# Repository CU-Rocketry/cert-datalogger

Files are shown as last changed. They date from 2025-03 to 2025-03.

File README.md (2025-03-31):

# cert-datalogger

Eggtimer Ion replica using ESP32-C3

## Features

- ESP32 MCU with WiFi and Bluetooth control and data export
- Pressure and temperature measurement
- 3.7V lithium battery compatibility
- Status LED and Buzzer

## Images

Screenshots for now:

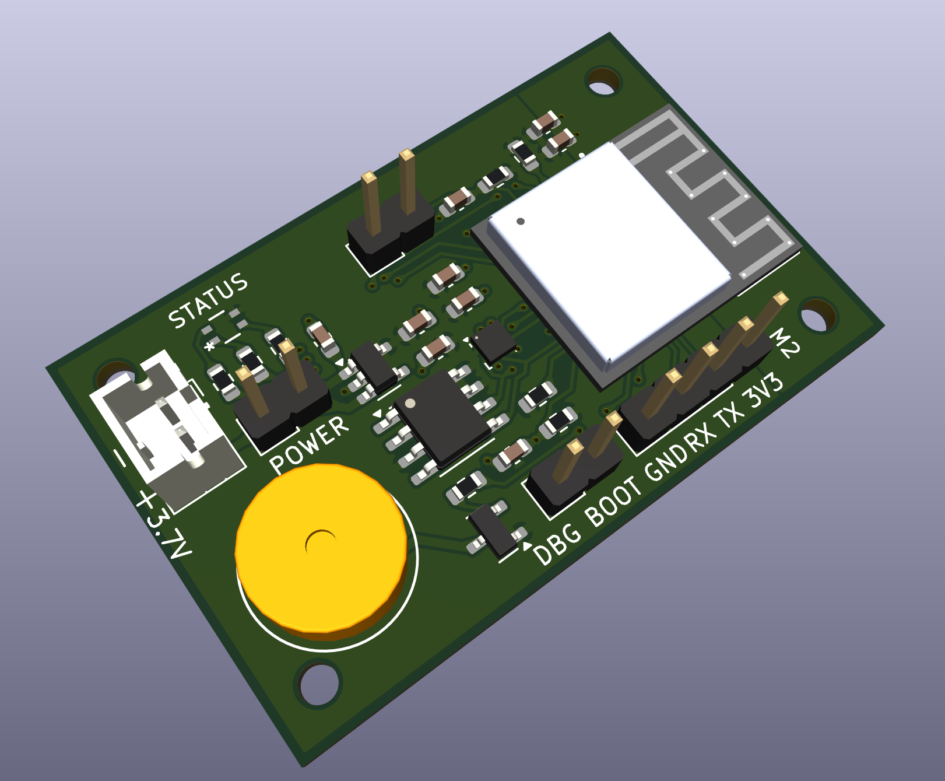
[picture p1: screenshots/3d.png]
3d pcb

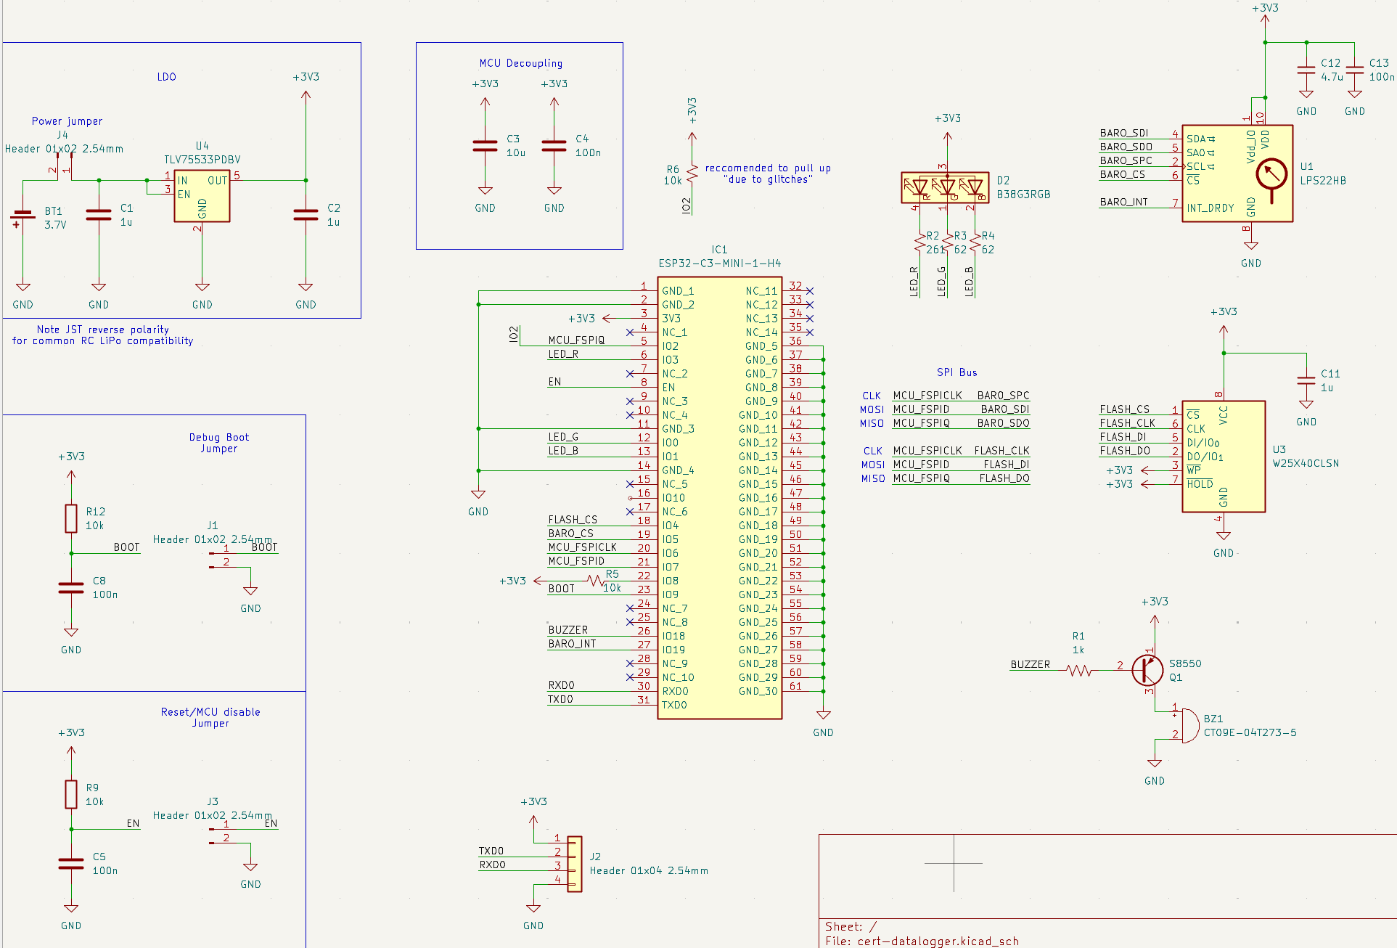
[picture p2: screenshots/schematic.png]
schematic

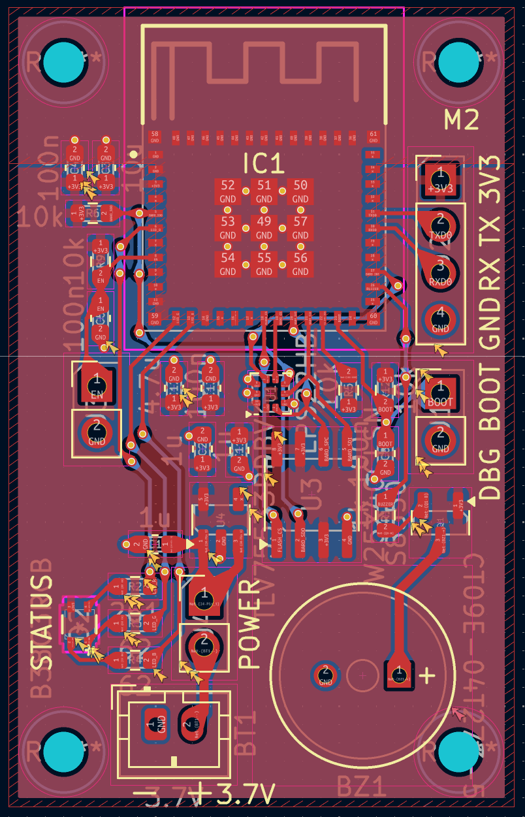
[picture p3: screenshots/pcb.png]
pcb


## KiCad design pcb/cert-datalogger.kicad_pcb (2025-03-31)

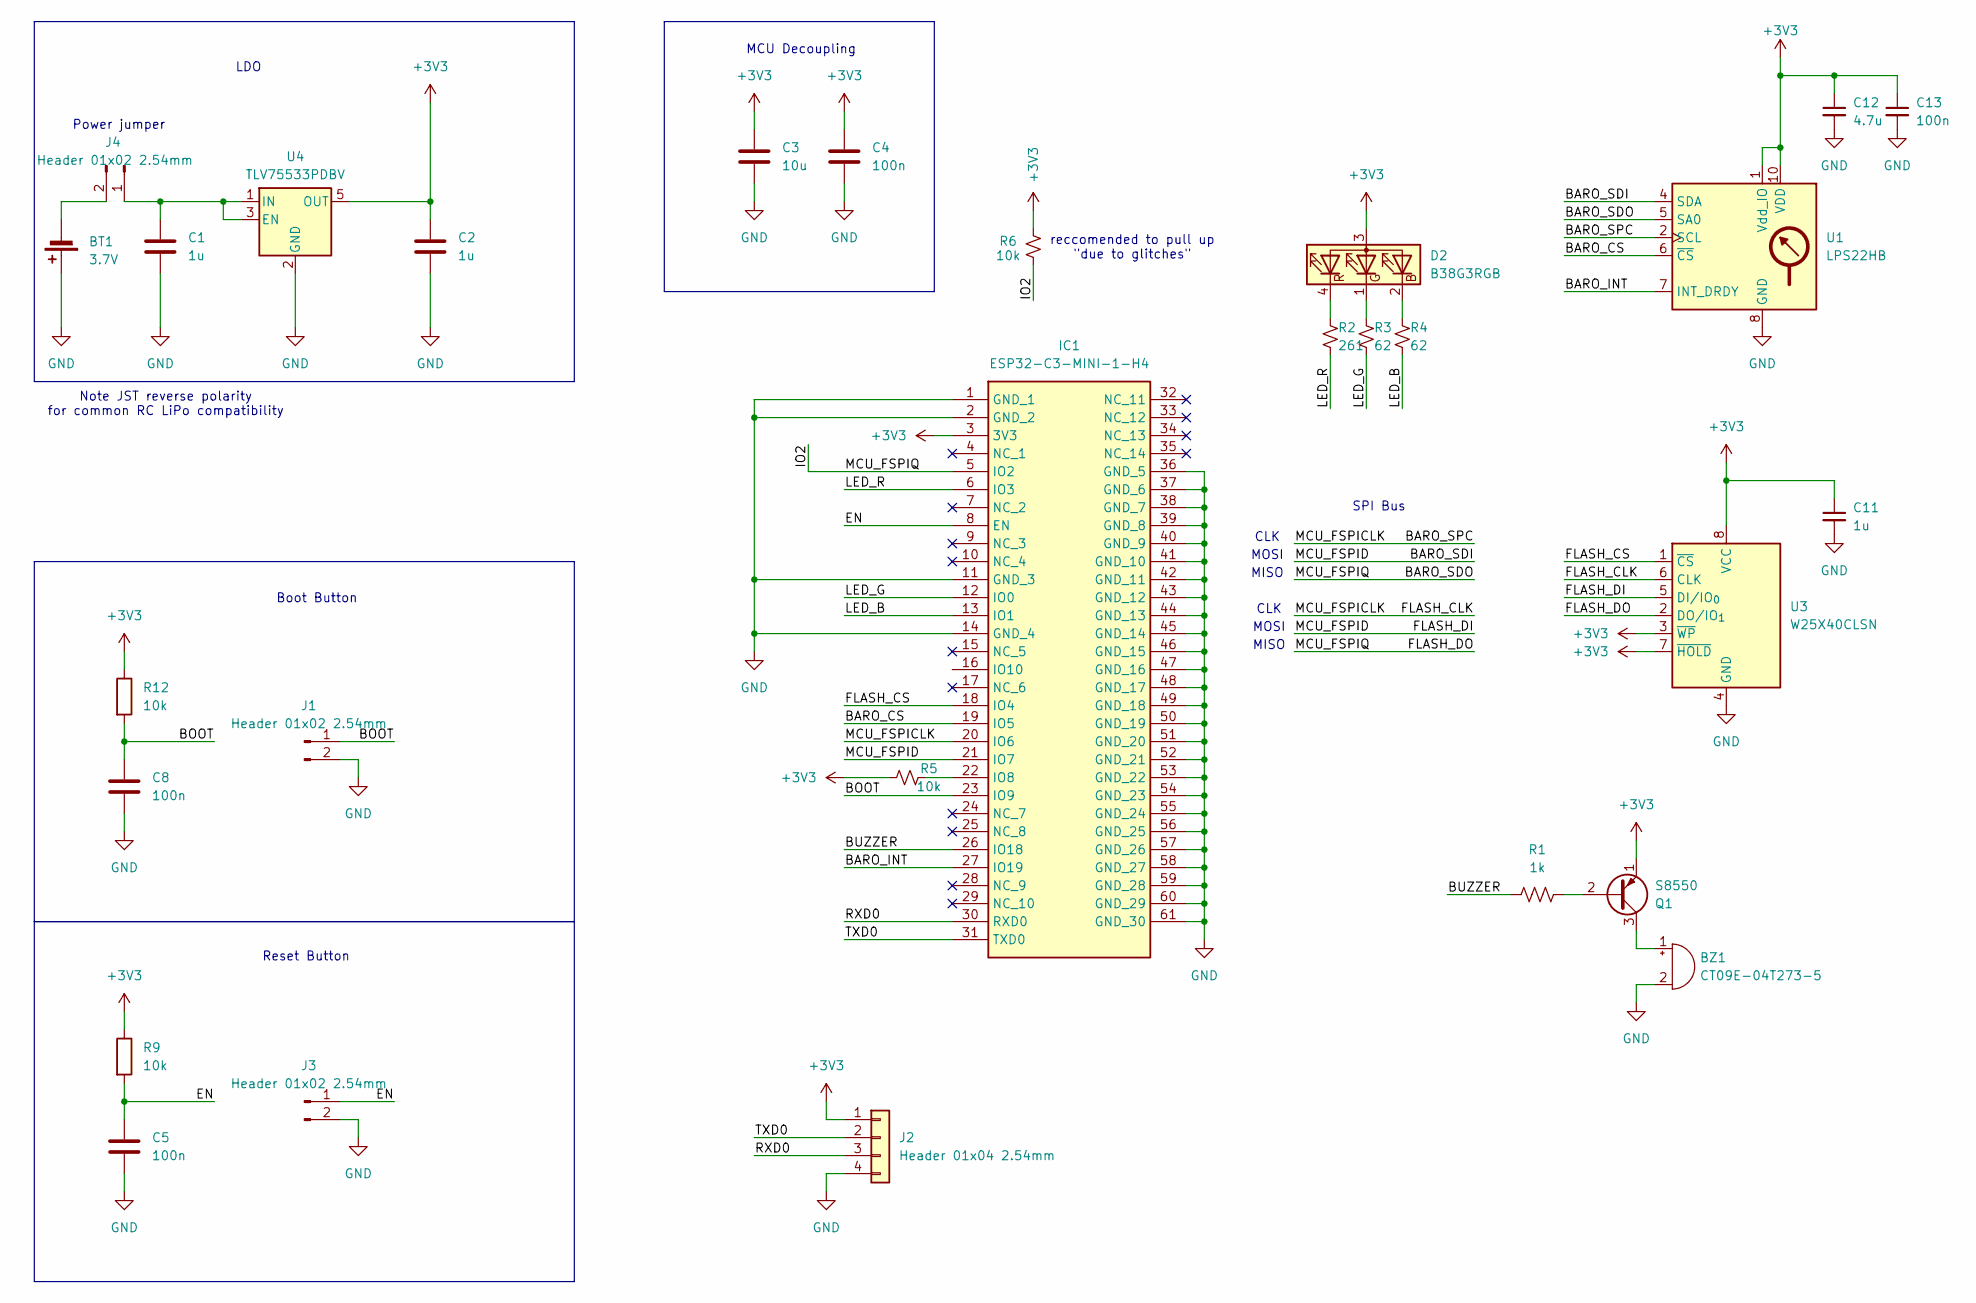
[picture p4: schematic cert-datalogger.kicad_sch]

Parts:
BT1: 3.7V; JST_PH_B2B-PH-K_1x02_P2.00mm_Vertical
BZ1: CT09E-04T273-5
C1, C2, C11: 1u; C_0603_1608Metric
C3: 10u; C_0603_1608Metric
C4, C5, C8, C13: 100n; C_0603_1608Metric
C12: 4.7u; C_0603_1608Metric
D2: B38G3RGB; B38G3RGB-10D0003H2U1930_HVK
IC1: ESP32-C3-MINI-1-H4; Mouser Part Number 356-ESP32-C3-MINI1H4
J1, J3, J4: Header 01x02 2.54mm; PinHeader_1x02_P2.54mm_Vertical
J2: Header 01x04 2.54mm; PinHeader_1x04_P2.54mm_Vertical
Q1: S8550; SOT-23
R1: 1k; R_0603_1608Metric
R2: 261; R_0603_1608Metric
R3, R4: 62; R_0603_1608Metric
R5, R6, R9, R12: 10k; R_0603_1608Metric
U1: LPS22HB; ST_HLGA-10_2x2mm_P0.5mm_LayoutBorder3x2y
U3: W25X40CLSN; SOIC-8_3.9x4.9mm_P1.27mm
U4: TLV75533PDBV; SOT-23-5

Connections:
+3V3: C2.1, C3.1, C4.1, C11.1, C12.1, C13.1, D2.3 (A), IC1.3 (3V3), J2.1, Q1.1 (E), R5.1, R6.1, R9.1, R12.1, U1.1 (Vdd_IO), U1.10 (VDD), U3.3 (~WP), U3.7 (~HOLD), U3.8 (VCC), U4.5 (OUT)
/BARO_CS: IC1.19 (IO5), U1.6 (~CS)
/BARO_INT: IC1.27 (IO19), U1.7 (INT_DRDY)
/BARO_SDI: IC1.21 (IO7), U1.4 (SDA), U3.5 (DI/IO_{0})
/BARO_SDO: IC1.5 (IO2), R6.2, U1.5 (SA0), U3.2 (DO/IO_{1})
/BARO_SPC: IC1.20 (IO6), U1.2 (SCL), U3.6 (CLK)
/BOOT: C8.1, IC1.23 (IO9), J1.1, R12.2
/BUZZER: IC1.26 (IO18), R1.1
/EN: C5.1, IC1.8 (EN), J3.1, R9.2
/FLASH_CS: IC1.18 (IO4), U3.1 (~CS)
/LED_B: IC1.13 (IO1), R4.2
/LED_G: IC1.12 (IO0), R3.2
/LED_R: IC1.6 (IO3), R2.2
/RXD0: IC1.30 (RXD0), J2.3
/TXD0: IC1.31 (TXD0), J2.2
GND: BT1.1 (+), BZ1.2 (-), C1.2, C2.2, C3.2, C4.2, C5.2, C8.2, C11.2, C12.2, C13.2, IC1.1 (GND_1), IC1.2 (GND_2), IC1.11 (GND_3), IC1.14 (GND_4), IC1.36 (GND_5), IC1.37 (GND_6), IC1.38 (GND_7), IC1.39 (GND_8), IC1.40 (GND_9), IC1.41 (GND_10), IC1.42 (GND_11), IC1.43 (GND_12), IC1.44 (GND_13), IC1.45 (GND_14), IC1.46 (GND_15), IC1.47 (GND_16), IC1.48 (GND_17), IC1.49 (GND_18), IC1.50 (GND_19), IC1.51 (GND_20), IC1.52 (GND_21), IC1.53 (GND_22), IC1.54 (GND_23), IC1.55 (GND_24), IC1.56 (GND_25), IC1.57 (GND_26), IC1.58 (GND_27), IC1.59 (GND_28), IC1.60 (GND_29), IC1.61 (GND_30), J1.2, J2.4, J3.2, U1.3 (GND), U1.8 (GND), U1.9 (GND), U3.4 (GND), U4.2 (GND)
unnamed: BT1.2 (-), J4.2
unnamed: BZ1.1 (+), Q1.3 (C)
unnamed: D2.2 (BK), R4.1
unnamed: D2.1 (GK), R3.1
unnamed: D2.4 (RK), R2.1
unnamed: IC1.22 (IO8), R5.2
unnamed: C1.1, J4.1, U4.1 (IN), U4.3 (EN)
unnamed: Q1.2 (B), R1.2

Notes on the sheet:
Reset Button
SPI Bus
MISO
LDO
Power jumper
Boot Button
reccomended to pull up "due to glitches"
Note JST reverse polarity for common RC LiPo compatibility
CLK
MOSI
MCU Decoupling

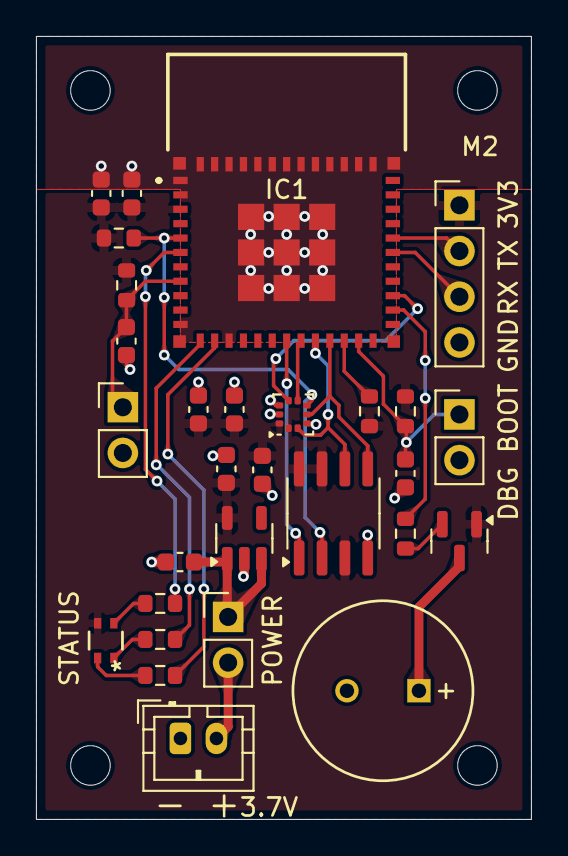
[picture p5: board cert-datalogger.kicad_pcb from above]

Board: 2 copper layers, 27.5 x 43.5 mm, 29 parts (0 on the bottom side), 24 nets.

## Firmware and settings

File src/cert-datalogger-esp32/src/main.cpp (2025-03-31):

#include <Arduino.h>
#include <SPI.h>

#define VSPI_MISO MISO
#define VSPI_MOSI MOSI
#define VSPI_SCLK SCK
#define VSPI_SS   SS

#define HSPI_MISO 12
#define HSPI_MOSI 13
#define HSPI_SCLK 14
#define HSPI_SS   15

#ifndef CONFIG_IDF_TARGET_ESP32
  #define VSPI FSPI
#endif

static const int spiClk = 1000000;  // 1 MHz

//uninitialized pointers to SPI objects
SPIClass *vspi = NULL;
SPIClass *hspi = NULL;

void spiCommand(SPIClass *spi, byte data) {
  //use it as you would the regular arduino SPI API
  spi->beginTransaction(SPISettings(spiClk, MSBFIRST, SPI_MODE0));
  digitalWrite(spi->pinSS(), LOW);  //pull SS slow to prep other end for transfer
  spi->transfer(data);
  digitalWrite(spi->pinSS(), HIGH);  //pull ss high to signify end of data transfer
  spi->endTransaction();
}

void setup() {
  // initialize SPI instances
  vspi = new SPIClass(VSPI);
  hspi = new SPIClass(HSPI);

  vspi->begin(VSPI_SCLK, VSPI_MISO, VSPI_MOSI, VSPI_SS);
  hspi->begin(HSPI_SCLK, HSPI_MISO, HSPI_MOSI, HSPI_SS);

  // setup slave select manually
  pinMode(VSPI_SS, OUTPUT);
  pinMode(HSPI_SS, OUTPUT);

  // init barometer
  LPS22HBSensor lp22hb(&vspi, VSPI_SS);
  lp22hb.begin();
  lp22hb.Enable();
}

// the loop function runs over and over again until power down or reset
void loop() {
  //use the SPI buses
  spiCommand(vspi, 0b01010101);  // junk data to illustrate usage
  spiCommand(hspi, 0b11001100);
  delay(100);
}

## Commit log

2025-03-31 Add PCB
    [cert-datalogger.kicad_pcb, cert-datalogger.kicad_sch]
2025-03-31 Update kicad-library-sigmondkukla
2025-03-31 Fix ESP32 3D model
    [cert-datalogger.kicad_pcb]
